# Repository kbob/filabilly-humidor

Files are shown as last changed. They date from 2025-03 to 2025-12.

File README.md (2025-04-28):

# FilaBilly Humidor

The FilaBilly Humidor (FBH) is a smart cabinet for 3D printer filament storage and humidity control.  It's based on an IKEA BILLY bookcase and contains an active dehumidifier.  It has lighting, environment sensors, and a display screen, and it is Internet enabled.

The FilaBilly Humidor is based on [ESPHome](https://esphome.io/).  It can be used as a standalone device or integrated into [Home Assistant](https://homeassistant.io/).

**Status:** Mostly vaporware.  Some materials have been acquired.

## FilaBilly Dehumidifier
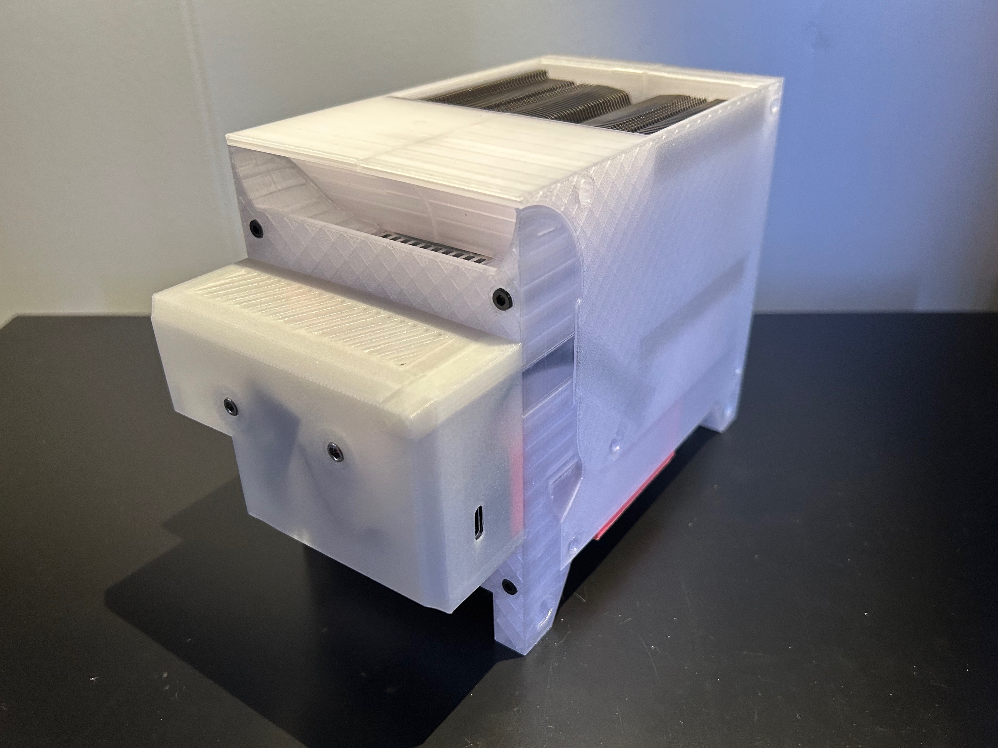
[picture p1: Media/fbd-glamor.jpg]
FilaBilly Dehumidifier


The FilaBilly Dehumidifier (FBD) is the dehumidifier component.  It is a compact active dehumidifier that is also Internet enabled.  The FBD can also be used without the FBH, either standalone or directly integrated into Home Assistant.  The FBD also uses ESPHome.

**Status:** Designed, printed, tested.

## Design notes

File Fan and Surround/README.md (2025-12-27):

# Fan and Surround

The Filabilly Humidor has a fan in the center shelf to move air from the lower to the upper chamber.  There is also a passive return for airflow in the opposite direction.  The `Fan Surround` directory has both.

The passive return surround holds a dummy fan that looks like another Noctua.  It's in the `Dummy Fan` directory.

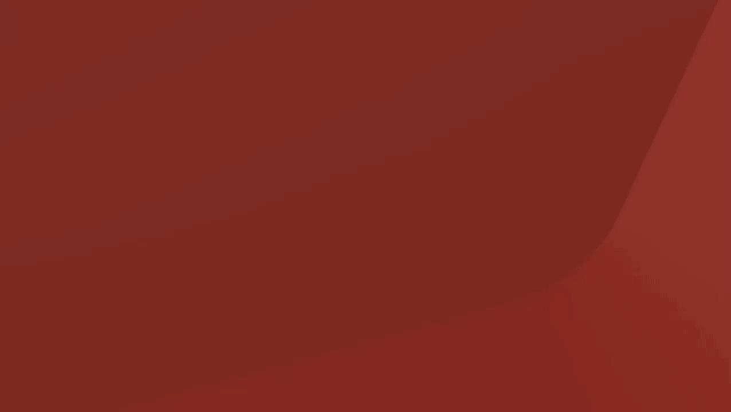
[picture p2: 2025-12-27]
Fan and Surround/Fan Surround/sequence.gif

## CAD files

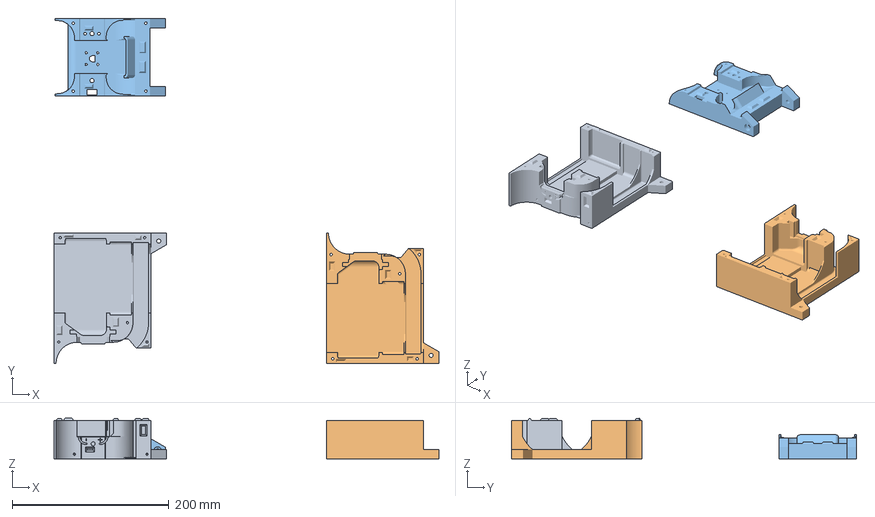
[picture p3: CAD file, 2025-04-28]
Dehumidifier/Printed Parts/3MF Files/PETG parts - 3 plates.3mf
491.8 x 440.7 x 52.2 mm
Housing Left Half.stl
Housing Right Half.stl
Housing Front.stl

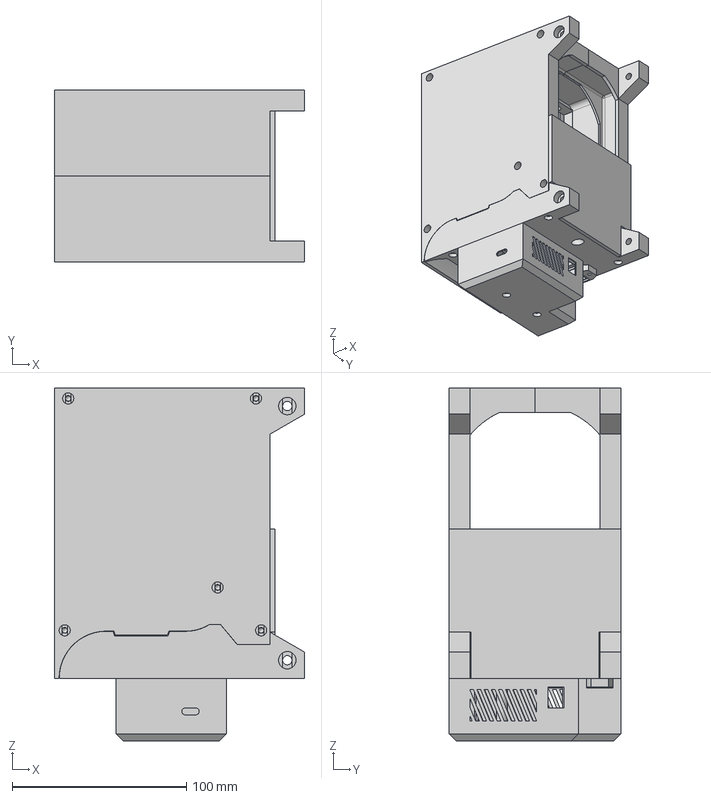
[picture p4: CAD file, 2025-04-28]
Dehumidifier/Printed Parts/CAD Files/Noctua Peltier Dehumidifier v37.step
143.8 x 98.7 x 202.7 mm
Seal Left
Seal Right
Electronics Cover
PCB Standoffs
Housing Right Half
Housing Left Half
Bottom Vent Slider

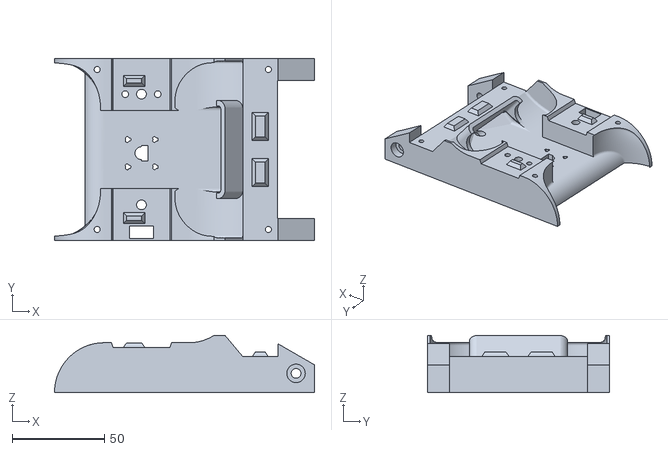
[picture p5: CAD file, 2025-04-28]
Dehumidifier/Printed Parts/STL Files/Housing Front.stl
141.0 x 98.7 x 30.9

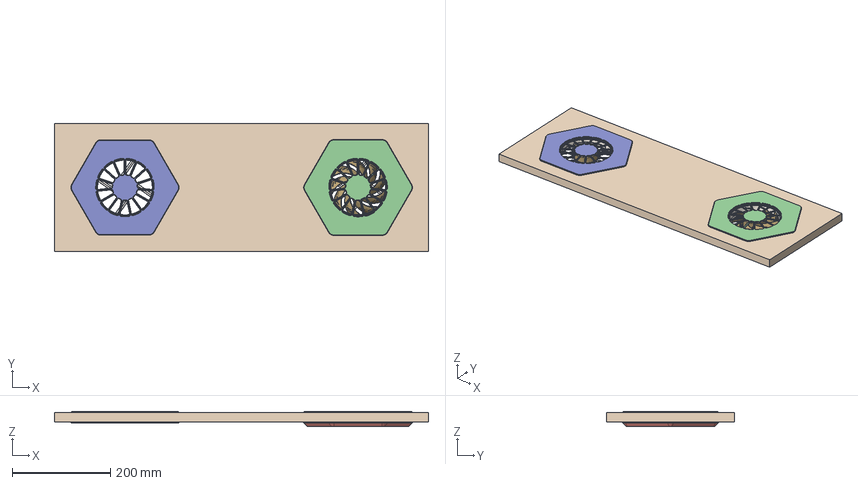
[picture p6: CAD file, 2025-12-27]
Fan and Surround/Dummy Fan/Shelf Fan Housing v15.step
760.0 x 260.0 x 29.5 mm
NOCTUA_NF-A12_FRAME
ANTI_VIBRATION_PAD x 8
NOCTUA_NF-A12_BLADES
FAN_HUB
Shelf
NOCTUA_NF-A12_FRAME_1
NOCTUA_NF-A12_BLADES_1
Dummy Surround

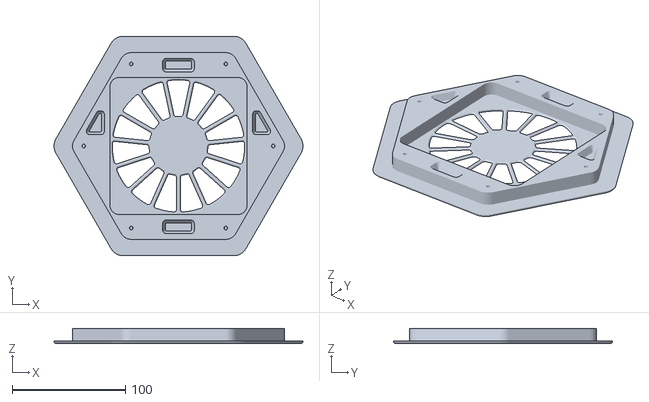
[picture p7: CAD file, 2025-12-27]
Fan and Surround/Fan Surround/Dummy Top.stl
220.0 x 193.9 x 13.0

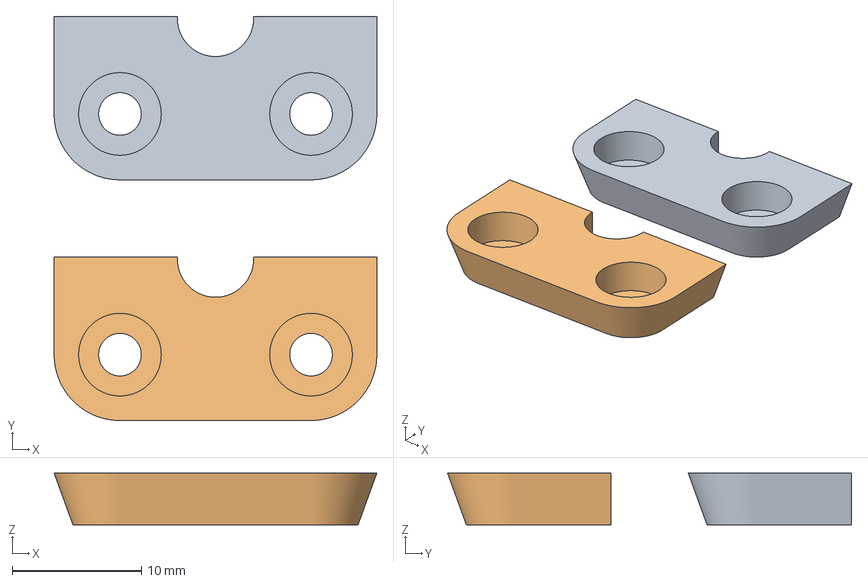
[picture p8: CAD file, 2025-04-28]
Dehumidifier/Printed Parts/3MF Files/TPU Parts - 1 plate.3mf
25.0 x 31.3 x 4.00 mm

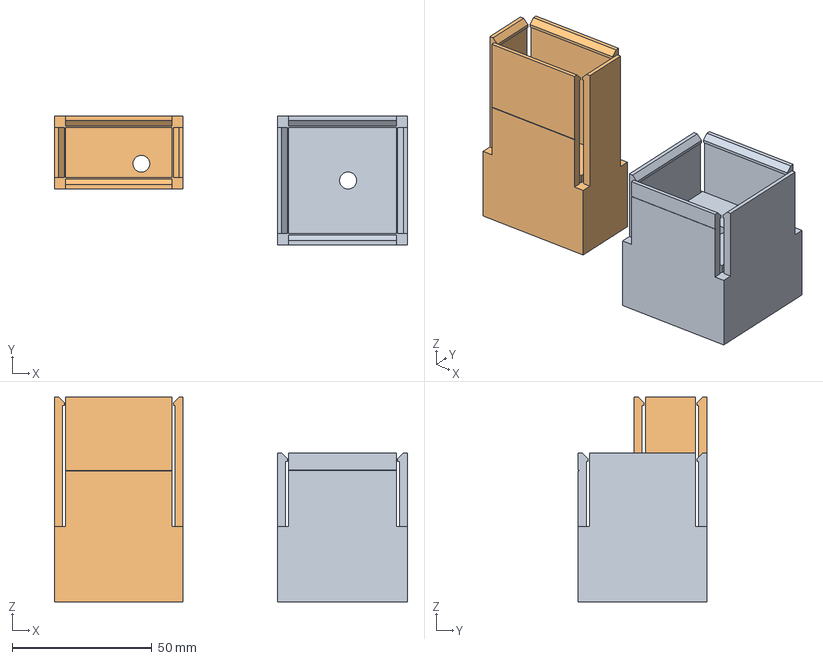
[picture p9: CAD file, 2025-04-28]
Dehumidifier/Printed Parts/CAD Files/Heatsink Drill Guide v4.step
126.2 x 46.0 x 73.2 mm

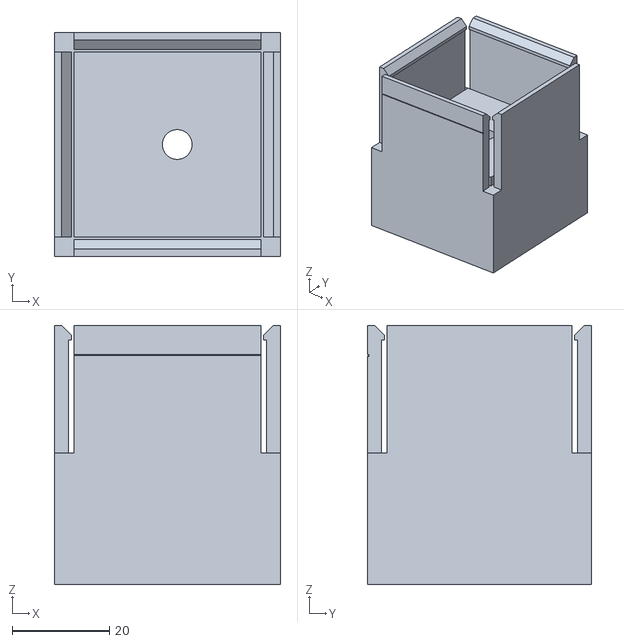
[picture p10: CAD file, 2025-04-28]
Dehumidifier/Printed Parts/STL Files/Heatsink Drill Guide.stl
46.5 x 46.0 x 53.2

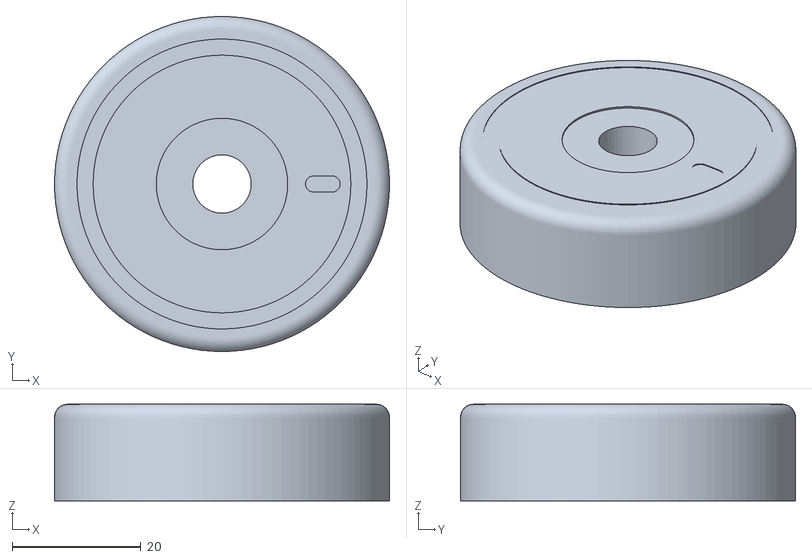
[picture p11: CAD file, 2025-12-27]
Fan and Surround/Dummy Fan/Dummy Fan Hub.stl
52.0 x 52.0 x 15.0

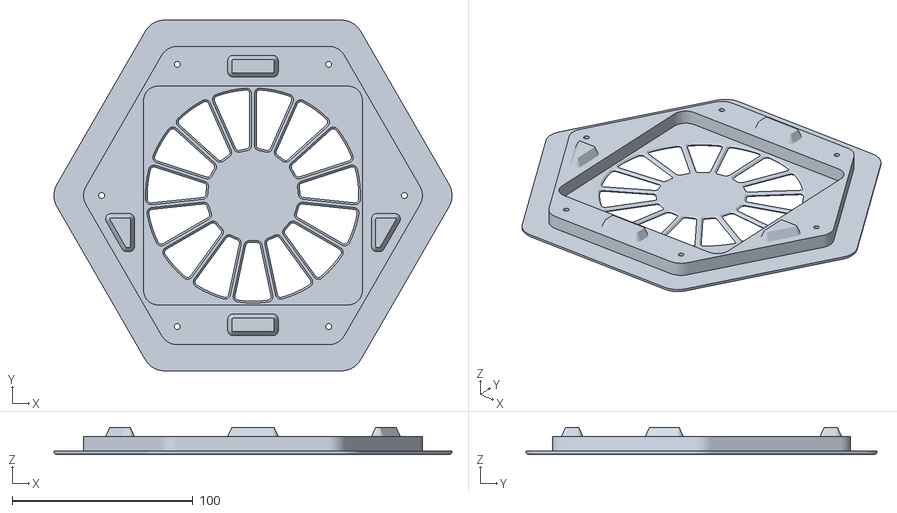
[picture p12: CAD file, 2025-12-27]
Fan and Surround/Fan Surround/Dummy Bottom.stl
220.0 x 193.9 x 15.0

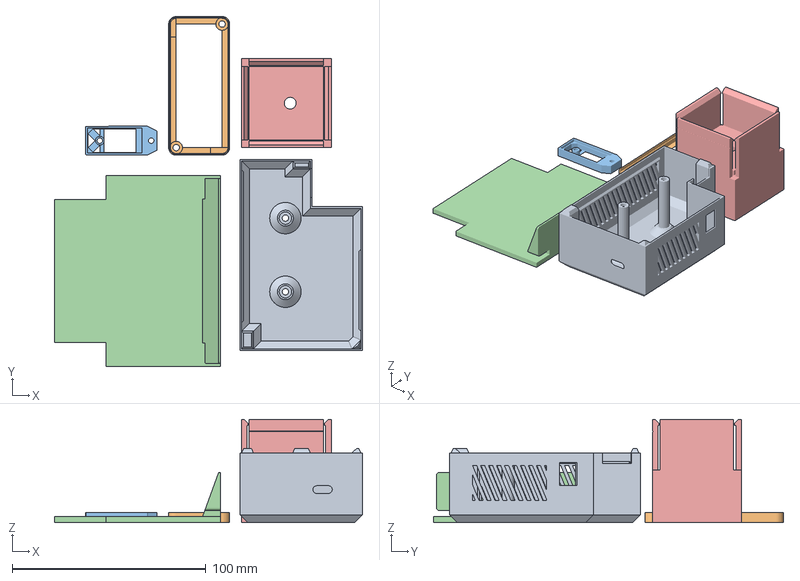
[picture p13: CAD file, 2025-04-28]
Dehumidifier/Printed Parts/3MF Files/PLA parts - 1 plate.3mf
159.0 x 180.7 x 53.2 mm
Electronics Cover.stl
PCB Standoff.stl
DHT22 Standoff.stl
Bottom Vent Slider.stl
Heatsink Drill Guide.stl

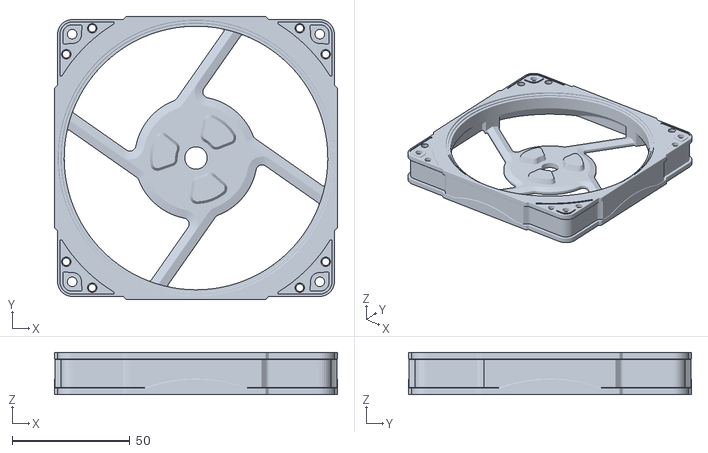
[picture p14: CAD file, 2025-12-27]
Fan and Surround/Dummy Fan/Dummy Fan Surround.stl
120.0 x 120.0 x 18.0

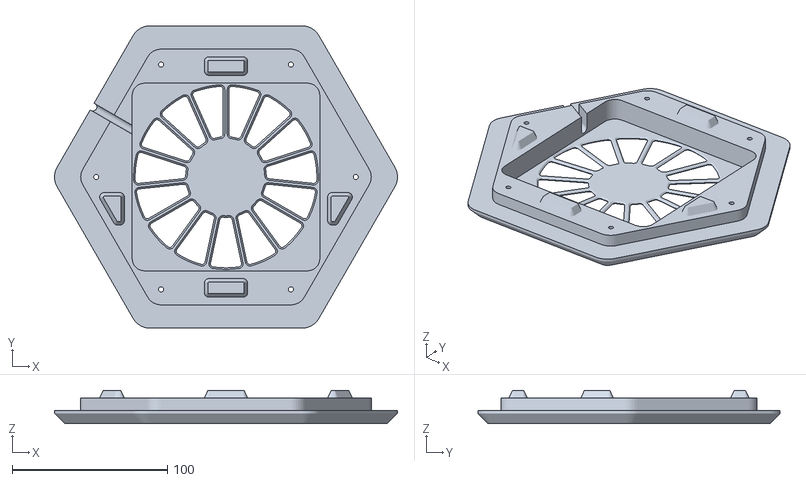
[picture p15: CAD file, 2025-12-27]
Fan and Surround/Fan Surround/Fan Housing Bottom.stl
221.1 x 194.9 x 21.5

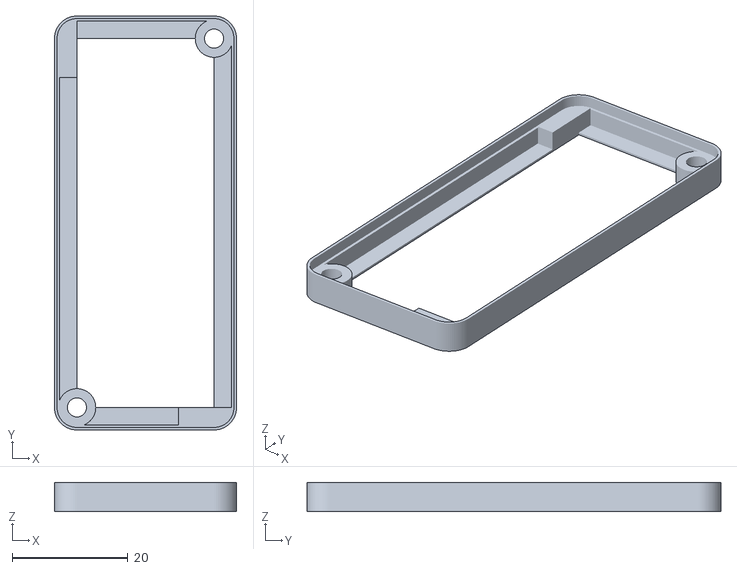
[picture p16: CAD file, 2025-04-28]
Dehumidifier/Printed Parts/STL Files/PCB Standoff.stl
31.5 x 71.6 x 5.10

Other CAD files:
Dehumidifier/Printed Parts/STL Files/2X Half Seal.stl
Fan and Surround/Fan Surround/Fan Housing Top.stl
Dehumidifier/Printed Parts/STL Files/Housing Left Half.stl
Fan and Surround/Fan Surround/Cutting Guide.stl
Dehumidifier/Printed Parts/CAD Files/Heatsink Drill Guide v4.f3d
Dehumidifier/Printed Parts/STL Files/Bottom Vent Slider.stl
Dehumidifier/Printed Parts/STL Files/DHT22 Standoff.stl
Dehumidifier/Printed Parts/STL Files/Electronics Cover.stl
Dehumidifier/Printed Parts/STL Files/Housing Right Half.stl

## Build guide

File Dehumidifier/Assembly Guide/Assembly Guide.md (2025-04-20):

# FilaBilly Dehumidifier Assembly Guide

## Overview

Welcome to the **FilaBilly Dehumidifier (FBD)**.  This is a compact smart device that extracts water from the air.  It is meant to be used in an airtight cabinet to create a low humidity environment to store 3D printer filament.

This is part of a larger project in progress, the **FilaBilly Humidor (FBH)**.  The FBH is based on the [FilaBilly](https://www.printables.com/model/660713-filabilly-filament-rack).  The FilaBilly turns an IKEA BILLY bookcase into a filament storage cabinet.  The FBH expands on the FilaBilly by sealing the cabinet and adding lighting, environment monitoring and control, and smart home integration.

The FilaBilly Dehumidifier is an ESPHome smart device based on an ESP32 micro controller.  It connects to your network using Wi-Fi.  You can control it directly with a web browser or integrate it into Home Assistant.  In the future, I intend to also be able to monitor and control it from the FilaBilly Humidor's micro controller.

The FilaBilly Dehumidifier includes a printed circuit board for the electronics.  All of the parts use through-holes[^1] for easy assembly, and all of the parts should be easy to source.

[^1]: With one exception. The optional QWIIC connector is surface mount.

The FilaBilly Dehumidifier is closely based on [Ben Krejci's filament dehumidifier](https://www.benkrejci.com/post/dehumidifier).  Ben gets credit for the overall design, the air and water routing through the box, and most of the ESPhome firmware.  I would have just used Ben's design except that he started with a CPU cooler that is no longer made.  So the FilaBilly Dehumidifier is designed to fit the Noctua NH-U9S cooler.

The FilaBilly Dehumidifier is a work in progress.  The mechanical assembly feels finished.  The ESPHome firmware is functional but missing some features.  I intend to design some brackets to clip it onto FilaBilly rails.  And the larger FilaBilly Humidor project is still mostly theoretical at this point.  Still, I'm publishing it in unfinished state because it's good enough to use.

## Bill of Materials

You will need these parts to build the FBD.  The Buy links are representative.  You may have parts on hand; you can certainly find the parts cheaper elsewhere.

### Printed Parts

| Quantity | Name | Material | Supports? |
|---:|:---|:---|:---:|
| 1 | Housing Left Half | PETG | Yes |
| 1 | Housing Right Half  | PETG | Yes |
| 1 | HeatsinkDrill Guide | any | - |
| 1 | Bottom Vent Slider  | any | Yes |
| 1 | Electronics Cover | any | - |
| 1 | PCB Standoff | any | - |
| 1 | DHT22 Standoff | any | - |
| 2 | Half Seal | TPU[^2]  | - |

[^2]: The seal halves will work best in TPU, but PETG may work.  They are designed to be deformed a little during assembly.  If you use PETG, you may have to file or trim them to fit.

### PCB Assembly Parts

The FBD includes a custom **printed circuit board (PCB)** to connect the ESP32 micro controller to the rest of the electronics.  This guide assumes you're familiar with the process of ordering PCBs and assembling electronics.  If not, the Internet is full of resources to get you started.

The PCB has space for a QWIIC connector, but it is not used.  If you want to add I²C peripherals such as an alternative humidity sensor, you can populate it.  You're on your own for mechanical packaging and ESPHome configuration if you do, though.

| Quantity | Description | Buy |
|---:|:---|:----|
| 1 | Printed Circuit Board | [OSH Park](https://oshpark.com/shared_projects/0QmItzAm) |
| 1 | MP1584 Regulator Module | [Amazon](https://www.amazon.com/dp/B08DHS5XVK) |
| 1 | IRLB8721 Power MOSFET | [Digikey](https://www.digikey.com/en/products/detail/infineon-technologies/irlb8721pbf/2127670) |
| 1 | PJ-102AH Barrel Jack | [Digikey](https://www.digikey.com/en/products/detail/same-sky-formerly-cui-devices/PJ-102AH/408448) |
| 1 | 2 pos 3.5mm terminal block | [Digikey](https://www.digikey.com/en/products/detail/w%C3%BCrth-elektronik/691214110002/2508516) |
| 2 | 7 pos female header 2.54mm | [Digikey](https://www.digikey.com/en/products/detail/sullins-connector-solutions/PPTC071LFBN-RC/810146) |
| 1 | 4 pos male header 2.54mm | [Digikey](https://www.digikey.com/en/products/detail/sullins-connector-solutions/PREC040SAAN-RC/2774814)<br>(40 pins, cut it to length) |
| 2 | 3 pos male header 2.54mm | (see above) |
| 4 | 2 pos male heder 2.54mm | (see above) |
| 1 | 10K 1/4w through hole resistor  | [Digikey](https://www.digikey.com/en/products/detail/stackpole-electronics-inc/CF14JT10K0/1741265) |
| 1 | 4.7K 1/4w through hole resistor | [Digikey](https://www.digikey.com/en/products/detail/stackpole-electronics-inc/CF14JT4K70/1741428) |

#### Optional

If you add the QWIIC connector, you will need these additional parts.

| Quantity | Description | Buy |
|---:|:---|:----|
| 2 | additional 4.7K resistors | (see above) |
| 1 | JST BM04B-SRSS-TB | [Digikey](https://www.digikey.com/en/products/detail/jst-sales-america-inc/BM04B-SRSS-TB/926696) |

### Other Parts

| Quantity | Description | Buy |
|---:|:---|:----|
| 1 | Noctua NH-U9S CPU Cooler | [Amazon](https://www.amazon.com/dp/B00TBHYYFK) |
| 1 | TEC-12705 Peltier Cooler | [Amazon](https://www.amazon.com/dp/B09GXDFW39) |
| 1 | aluminum heatsink, 40x40x20mm | [Amazon](https://www.amazon.com/dp/B07FXP35FW) |
| 1 | thermal paste | [Amazon](https://www.amazon.com/dp/B07L9BDY3T/) |
| 1 | Seeed XAIO ESP32C3 | [Seeed Studio](https://www.seeedstudio.com/Seeed-XIAO-ESP32C3-p-5431.html) |
| 1 | DHT22 temperature/humidity module | [Amazon](https://www.amazon.com/dp/B09TKTWXH1) |
| 1 | DS18B20 temperature probe | [Amazon](https://www.amazon.com/dp/B00M1PM55K) |
| 1 | 12V 5A power supply | [Amazon](https://www.amazon.com/dp/B0CW2PJQLJ/) |
| 1 | silicone tubing | [Amazon](https://www.amazon.com/dp/B0957KZVGG/) |
| 1 | 3 conductor female-female cable | [Amazon](https://www.amazon.com/dp/B07GD312VG)<br>(tear off three strands) |
| 2 | ferrules, 22awg | [Amazon](https://www.amazon.com/dp/B0BJD5796C) |
| 2 | M5 nylon lock nuts | |
| 2 | M5x30 SHCS machine screws | |
| 2 | M3x40 SHCS machine screws | |
| 4 | M3x30 SHCS machine screws | |
| 5 | M3x16 SHCS machine screws | |
| 2 | M3x10 SHCS machine screws | |
| 4 | M3x8 SHCS machine screws | |
| 2 | M2.5x10 SHCS machine screws | |

## Parts Preparation

### Deburr the PCB

If the PCB has "mouse bite" burrs around its edges, file them smooth until the PCB fits into the PCB Standoff printed part.

### Remove supports and clean parts

Remove the supports from the printed parts that have them.  The easiest way to clear supports from the tube in the Housing Right Half is to push them out with a long thin screwdriver.

It will also help to run screws through all the screw holes to clean them up until the screws slide through easily.  Don't clean up the blind holes &mdash; the screws need to bite into the plastic there.

Don't forget to clean the M5 holes in the dehumidifier feet.

### Drill heatsink

Use the Heatsink Drill Guide to drill a hole in between the fins of the heatsink.  Drill all the way to the heatsink base, but not beyond.  There is an etched line on the drill guide showing how far to drill.  Test fit the DS18B20 temperature probe and ensure it goes all the way in and contacts the heatsink base.  I used a 15/64" (5.95mm) bit, and I had to wobble it to enlarge the hole.  A 6mm bit would probably be ideal.

### Separate fan from CPU cooler

Unclip the wire clips from the Noctua NH-U9S CPU cooler and remove the fan.  Discard the clips.

### Remove clamp from CPU cooler

Insert a long Phillips screwdriver into the hole in the CPU cooler fans and unscrew the clamp.  Remove the clamp and discard it.

### Identify hot and cold sides of TEC

Briefly connect the TEC Peltier unit to a power supply and find out which side gets cold.  Label it or remember.  Mine has text printed on the cold side.

### Install ESPHome configuration

Before installing the XIAO into the FBD, install the ESPHome configuration and attach it to your Wi-Fi.  This guide doesn't cover ESPHome installation; see [the ESPHome documentation](https://esphome.io/) for info.

Verify that you can access the ESP32's web server now.

## Building the PCB Assembly

### Solder Components

Solder the components onto the PCB in this order.

 1. Male Headers.  You can use a breadboard to align most of the male headers while you solder them.
 2. Resistors
 3. QWIIC connector (optional)
 4. Female headers
 5. 5V regulator (MP1584)
 6. Terminal block
 7. Barrel jack
 8. Power MOSFET

### Set Voltage

Before attaching the XIAO, attach the 12V power supply and adjust the MP1584 regulator to 5 volts.

### Install XIAO

Plug the XIAO board in to the female headers.  Note that you should not attach the USB while the XIAO is in place.  For configuration updates, either use Wi-Fi or remove the XIAO before attaching USB.

## Assembly

This section shows the steps to assemble the parts.

### Insert M5 nuts

Insert the M5 nylon lock nuts into the housing halves.  Put an M5 screw through the hole, screw the nut onto it, and pull it back out until the nut is seated flush.

Note: the nuts are held in by friction.  Be careful not to dislodge them from here on.

### Insert NH-U9S into Housing Left Half

It will fit.  It has to be aligned just so, then it drops in.

### Insert fan into Housing Left Half

Orient the fan so the it blows air into the fins, and the cable is at the position shown.

### Affix TEC

Orient the TEC Peltier unit so that its hot side is against the CPU block and its wires fit into the slots in the Housing Left Half.  Apply enough thermal paste to make a thin layer over the whole mating surface and press it into place.
 
### Push Housing Right Half On

Feed the fan wire through the tunnel in the Housing Right Half.  Be careful not to pinch the wire, and lower the right half onto the assemblied parts.  It will fit.  When it does, it will drop on.  It may be slightly open at the back (1mm or less), that's okay.

### Screw the housing halves together

Use five M3x16 screws.  You should be able to pull the housing halves together to close any gap between them.  If not, something is probably pinched inside.  Open it up and correct the problem.

### Attach the Bottom Vent Slider

Put the Bottom Vent Slider in diagonally, then rotate it into position.

The vent slider is adjustable.  Start with it covering about half of the fan.

### Affix the heatsink and temperature probe

Push the temperature probe all the way into the heatsink so that it is contacting the heatsink base.  Orient the heatsink so that the fins are horizontal and the probe is slightly above center.  Apply thermal paste and stick it on.

### Attach the Housing Front

Feed the four wires through the holes in the Housing Front.  Push the Housing Front against the rest of the assembly.  Verify that the temperature probe lines up with its hole.

**Carefully** insert the M3x30 screws into the big holes and engage the nuts.  Do not push the nuts out of place.  Screw the screws down but not tight yet.

Insert four M3x30 screws into the four small holes and tighten them.  Then go back and tighten the M5 screws until the gap between the Housing Front and the Housing Left/Right Half is closed.

The M5 screws press the heatsink, TEC, and CPU cooler together to ensure a good thermal bond.

### Seal the temperature probe hole

Put the two Half Seals in and screw them down with four M3x8 screws.

Note.  The probe should stick out about as far as shown.  If it's more, then the probe may not be against the heatsink base.

### Install PCB, DHT22, and standoffs

Fit the PCB and the DHT22 into their standoffs.  Note the orientation of the PCB on its standoff.  Attach the PCB with two M3x10 screws, and attach the DHT22 with two M2.5x10 screws.

### Connect TEC wires

Cut the wires to length.  Install a ferrule on each wire.  Screw the ferrules into the terminal block on the PCB, and mind the polarity.

Note that the holes in the Housing Front are big enough to pass the ferrules through if you need to disassemble the dehumidifier.

### Connect temperature probe wires

Cut the wires on the DS18B20 temperature probe to length.  Crimp on 3 female Dupont pins and a connector.  Note the pinout as shown in the schematic or back side of the PCB.  Plug it into the PCB.

### Connect fan wires

The fan already has a compatible connector.  Note that Pin 1 on the connector is Pin 4 on the PCB.  Check the pinout.

### Connect DHT22 wires

Use the female-to-female cable to attach the DHT22 to the PCB.  Note the pinout.

### Attach the Electronics Cover

No, really.  Leave the Electronics Cover off for now.  You'll need access.  Just verify that it fits.  You'll have to mash things together; don't pinch the antenna or any wires.  Secure the cover with two M3x40 screws.

### Attach the drain tube

Spread some silicone caulk around the tip of the drain tube, then insert it into the drain hole.  Let it set according to the caulk instructions.

### Test

Dunno.  Mine worked on the first try, because I'd tested everything on a breadboard.  Attach power, look for smoke, listen for the fan, put your finger on the heatsink and see whether it's getting cold.  Connect to the ESP32's web server and see whether the sensor values look sane.  Try turning it off and on from the web interface.  Debug as needed.

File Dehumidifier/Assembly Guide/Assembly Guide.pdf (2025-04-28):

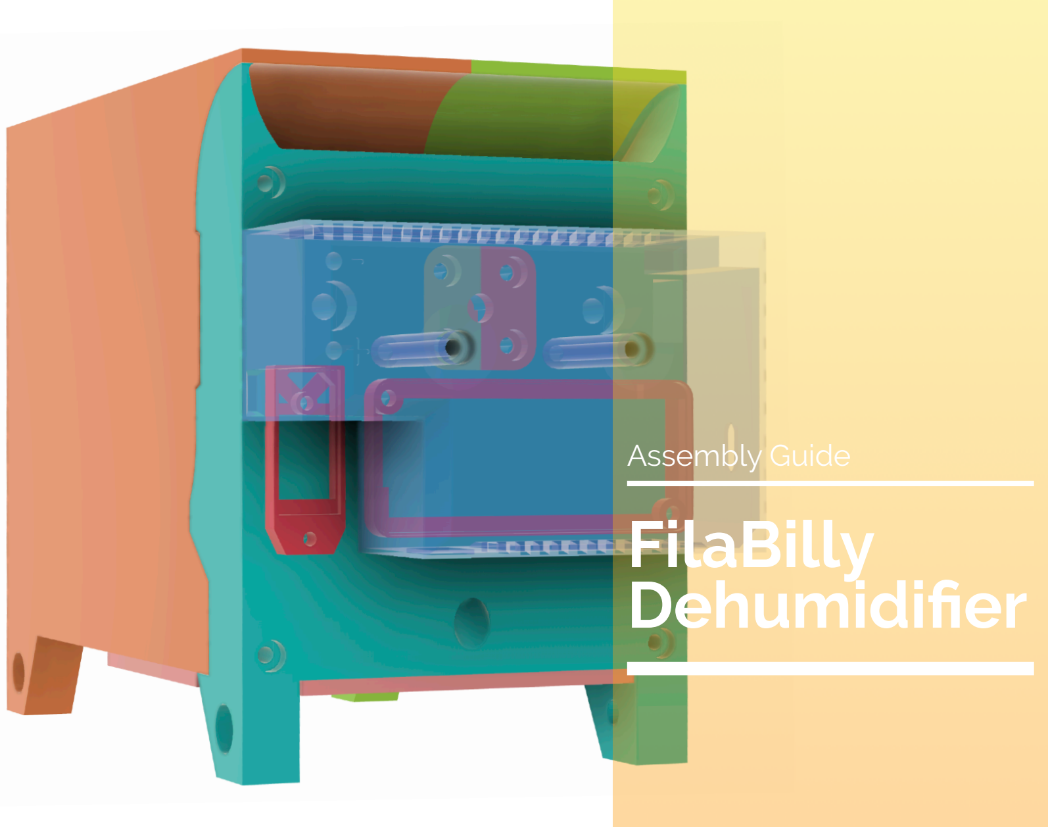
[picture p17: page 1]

# FilaBilly Dehumidifier

## Assembly Guide

## Overview

Welcome to the FilaBilly Dehumidifier (FBD). This is a compact smart device that extracts water from the air. It is meant to be used in an airtight cabinet to create a low humidity environment to store 3D printer filament.

This is part of a larger project in progress, the FilaBilly Humidor (FBH). The FBH is based on the FilaBilly. (https://www.printables.com/model/660713-filabilly-filament-rack) The FilaBilly turns an IKEA BILLY bookcase into a filament storage cabinet. The FBH expands on the FilaBilly by sealing the cabinet and adding lighting, environment monitoring and control, and smart home integration.

The FilaBilly Dehumidifier is an ESPHome smart device based on an ESP32 micro controller. It connects to your network using Wi-Fi. You can control it directly with a web browser or integrate it into Home Assistant. In the future, I intend to also be able to monitor and control it from the FilaBilly Humidor's micro controller.

The FilaBilly Dehumidifier includes a printed circuit board for the electronics. All of the parts use through-holes¹ for easy assembly , and all of the ¹ parts should be easy to source.

The FilaBilly Dehumidifier is closely based on Ben Krejci's filament dehumidifier. (https://www.benkrejci.com/post/dehumidifier) Ben gets credit for the overall design, the air and water routing through the box, and most of the ESPhome firmware. I would have just used Ben's design except that he started with a CPU cooler that is no longer made. So the FilaBilly Dehumidifier is designed to fit the Noctua NH-U9S cooler.

The FilaBilly Dehumidifier is a work in progress. The mechanical assembly feels finished. The ESPHome firmware is functional but missing some features. I intend to design some brackets to clip it onto FilaBilly rails. And the larger FilaBilly Humidor project is still mostly theoretical at this point. Still, I'm publishing it in unfinished state because it's good enough to use.

With one exception. The optional QWIIC connector is surface mount. ¹ Page 2 of 35

## Bill of Materials

You will need these parts to build the FBD. The Buy links are representative. You may have parts on hand; you can certainly find the parts cheaper elsewhere.

### Printed Parts

The seal halves will work best in TPU, but PETG may work. They are designed to be deformed a little during assembly. If you use PETG, you may have to file or trim them to fit.

Page 3 of 35

Quantity | Name | Material | Supports?
1 | Housing Left Half | PETG | Yes
1 | Housing Right Half | PETG | Yes
1 | Housing Front | PETG | Yes
1 | Electronics Cover | any | -
1 | PCB Standoff | any | -
1 | DHT22 Standoff | any | -
1 | Bottom Vent Slider | any | Yes
1 | Heatsink Drill Guide | any | -
2 | Half Seal | TPU | -

### PCB Assembly Parts

The FBD includes a custom printed circuit board (PCB) to connect the ESP32 micro controller to the rest of the electronics. This guide assumes you're familiar with the process of ordering PCBs and assembling electronics. If not, the Internet is full of resources to get you started.
Quantity | Description | Buy
1 | Printed Circuit Board | OSH Park (https://oshpark.com/shared_projects/0QmItzAm)
1 | MP1584 Regulator Module | Amazon (https://www.amazon.com/dp/B08DHS5XVK)
1 | IRLB8721 Power MOSFET | Digikey (https://www.digikey.com/en/products/detail/infineon-technologies/irlb8721pbf/2127670)
1 | PJ-102AH Barrel Jack | Digikey (https://www.digikey.com/en/products/detail/same-sky-formerly-cui-devices/PJ-102AH/408448)
1 | 2 pos 3.5mm terminal block | Digikey (https://www.digikey.com/en/products/detail/w%C3%BCrth-elektronik/691214110002/2508516)
2 | 7 pos female header 2.54mm | Digikey (https://www.digikey.com/en/products/detail/sullins-connector-solutions/PPTC071LFBN-RC/810146)
1 | 4 pos male header 2.54mm | Digikey (https://www.digikey.com/en/products/detail/sullins-connector-solutions/PREC040SAAN-RC/2774814) (40 pins, cut it to length)
2 | 3 pos male header 2.54mm | (see above)
4 | 2 pos male heder 2.54mm | (see above)
1 | 10K 1/4w through hole resistor | Digikey (https://www.digikey.com/en/products/detail/stackpole-electronics-inc/CF14JT10K0/1741265)
1 | 4.7K 1/4w through hole resistor | Digikey (https://www.digikey.com/en/products/detail/stackpole-electronics-inc/CF14JT4K70/1741428) Page 4 of 35

### Optional PCB Parts

The PCB has space for a QWIIC connector, but it is not used. If you want to add I²C peripherals such as an alternative humidity sensor, you can populate it.

You're on your own for mechanical packaging and ESPHome configuration if you do, though. If you add the QWIIC connector, you will need these additional parts.

Page 5 of 35

Quantity | Description | Buy
2 | additional 4.7K resistors | (see above)
1 | JST BM04B-SRSS-TB | Digikey (https://www.digikey.com/en/products/detail/jst-sales-america-inc/BM04B-SRSS-TB/926696)

### Other Parts

Page 6 of 35

Quantity | Description | Buy
1 | Noctua NH-U9S CPU Cooler | Amazon (https://www.amazon.com/dp/B00TBHYYFK)
1 | TEC-12705 Peltier Cooler | Amazon (https://www.amazon.com/dp/B09GXDFW39)
1 | aluminum heatsink, 40x40x20mm | Amazon (https://www.amazon.com/dp/B07FXP35FW)
1 | thermal paste | Amazon (https://www.amazon.com/dp/B07L9BDY3T/)
1 | Seeed XAIO ESP32C3 | Seeed Studio (https://www.seeedstudio.com/Seeed-XIAO-ESP32C3-p-5431.html)
1 | DHT22 temperature/humidity module | Amazon (https://www.amazon.com/dp/B09TKTWXH1)
1 | DS18B20 temperature probe | Amazon (https://www.amazon.com/dp/B00M1PM55K)
1 | 12V 5A power supply | Amazon (https://www.amazon.com/dp/B0CW2PJQLJ/)
1 | silicone tubing | Amazon (https://www.amazon.com/dp/B0957KZVGG/)
1 | 3 conductor female-female cable | Amazon (https://www.amazon.com/dp/B07GD312VG) (tear off three strands)
2 | ferrules, 22awg | Amazon (https://www.amazon.com/dp/B0BJD5796C)

Continued on next page

Page 7 of 35

Other Parts, continued
Quantity | Description | Buy
2 | M5 nylon lock nuts
2 | M5×30 SHCS machine screws
2 | M3×40 SHCS machine screws
4 | M3×30 SHCS machine screws
5 | M3×16 SHCS machine screws
2 | M3×10 SHCS machine screws
4 | M3×8 SHCS machine screws
2 | M2.5x10 SHCS machine screws

## Parts Preparation

### Deburr the PCB

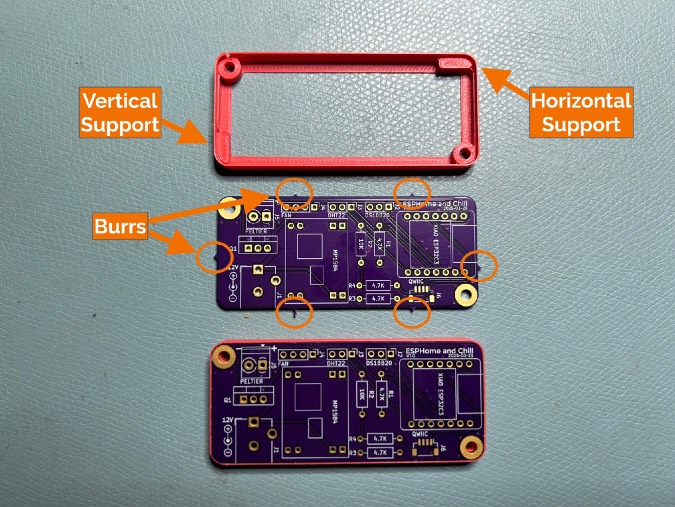
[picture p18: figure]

If the PCB has “mouse bite” burrs around its edges, trim and file them smooth until the PCB fits into the PCB Standoff printed part. Note the standoff orientation. The horizontal support goes under the "ESPHome and Chill" text, and the vertical support goes under the barrel jack polarity mark.

Page 8 of 35

### Remove supports and clean parts

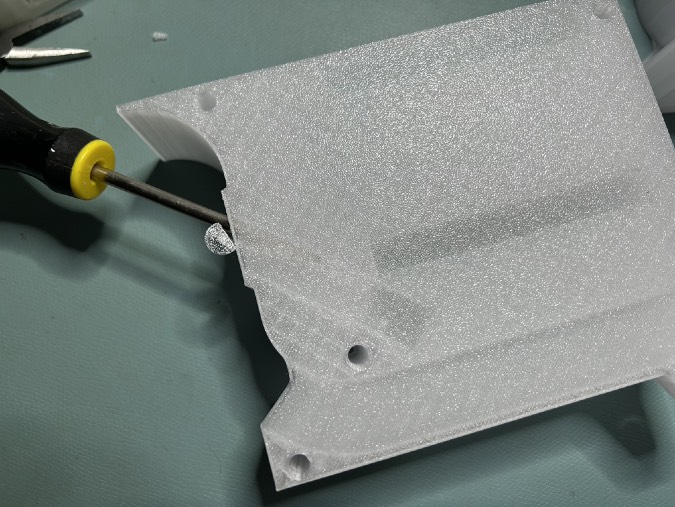
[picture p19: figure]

Remove the supports from the printed parts that have them. The easiest way to clear supports from the tube in the Housing Right Half is to push them out with a long thin screwdriver.

It will also help to run screws through all the screw holes to clean them up until the screws slide through easily. Don't clean up the blind holes — the screws need to bite into the plastic there.

Don't forget to clean the M5 holes in the dehumidifier feet.

Page 9 of 35

### Drill heatsink

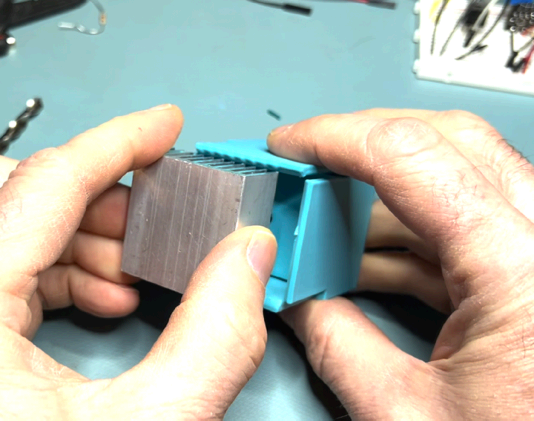
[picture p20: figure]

Use the Heatsink Drill Guide to drill a hole in between the fins of the heatsink. Put the heatsink into the drill guide fins down. Orient it so the drill hole does not hit the center fin. The heatsink will snap into place.

Drill through the hole, all the way to the heatsink base, but not beyond. There is an etched line on the drill guide showing how far to drill.

Test fit the DS18B20 temperature probe and ensure it goes all the way in and contacts the heatsink base. I used a 15/64" (5.95mm) drill bit, and I had to wobble it to enlarge the hole. A 6mm bit would probably be ideal.

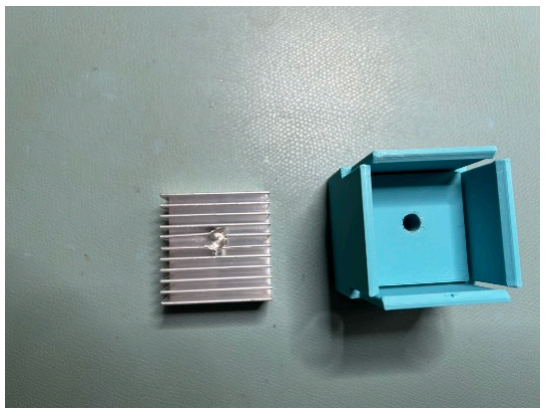
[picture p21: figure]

Page 10 of 35

### Separate fan from CPU cooler

Unclip the wire clips from the Noctua NH-U9S CPU cooler and remove the fan. Discard the clips.

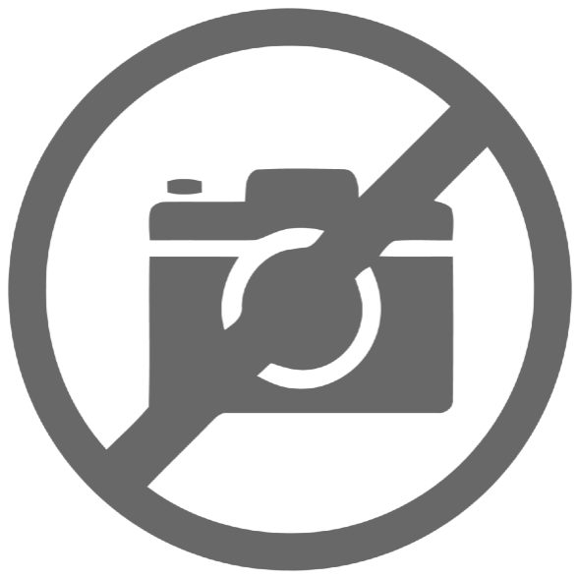
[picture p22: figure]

Page 11 of 35

No photo, sorry.

### Remove clamp from CPU cooler

Insert a long Phillips screwdriver into the hole in the CPU cooler fans and unscrew the clamp. Remove the clamp and discard it.

Page 12 of 35

No photo, sorry.

### Identify hot and cold sides of TEC

Briefly connect the TEC Peltier unit to a power supply and find out which side gets cold. Label it or remember. Mine has text printed on the cold side.

Page 13 of 35

No photo, sorry.

### Install ESPHome configuration

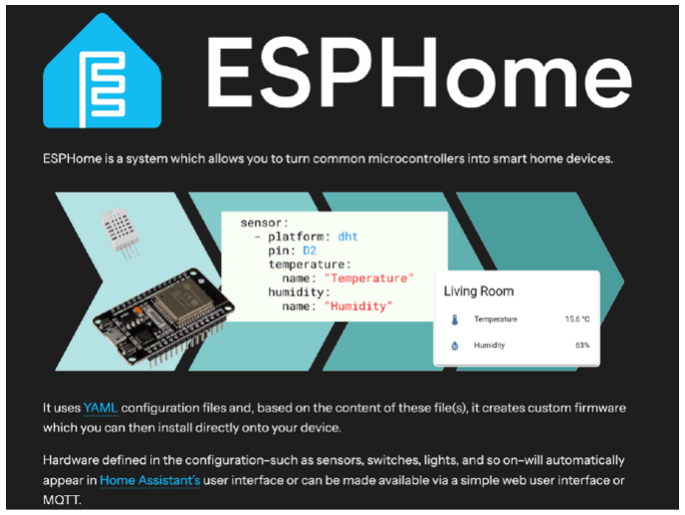
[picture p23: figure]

Before installing the XIAO into the FBD, install the ESPHome configuration and attach it to your Wi-Fi. This guide doesn't cover ESPHome installation; see the ESPHome documentation (https://esphome.io/) for info.

Verify that you can access the ESP32's web server.

Page 14 of 35

## Building the PCB Assembly

### Solder Components

Solder the components onto the PCB in this order.

1. Male Headers. You can use a breadboard to align most of the male headers while you solder them.
2. Resistors
3. QWIIC connector (optional)
4. Female headers
5. 5V regulator (MP1584)
6. Terminal block
7. Barrel jack
8. Power MOSFET

### Set Voltage

Before attaching the XIAO, attach the 12V power supply and adjust the MP1584 regulator to 5 volts.

### Install XIAO

Ensure the XIAO already has ESPHome configured. Plug the XIAO board in to the female headers.

Page 15 of 35

## Assembly

This section shows the steps to assemble the parts.

### Insert M5 nuts

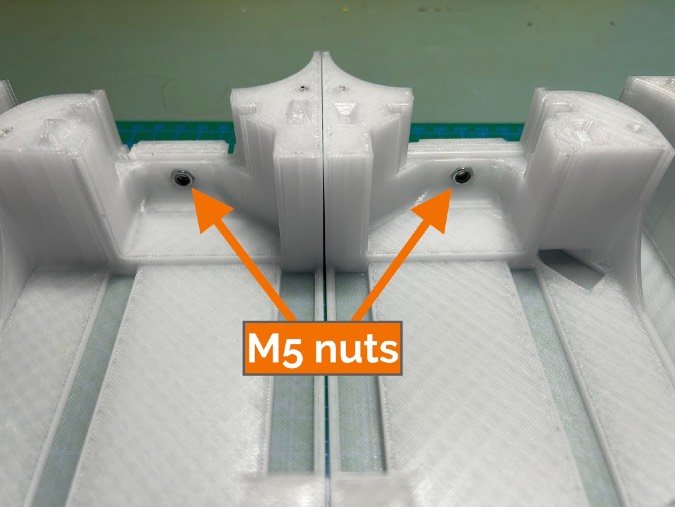
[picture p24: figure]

Insert the M5 nylon lock nuts into the housing halves. Put an M5 screw through the hole, screw the nut onto it, and pull it back out until the nut is seated flush.

The nuts are held in by friction. Be careful not to dislodge them from here on.

Page 16 of 35

### Insert NH-U9S into Housing Left Half

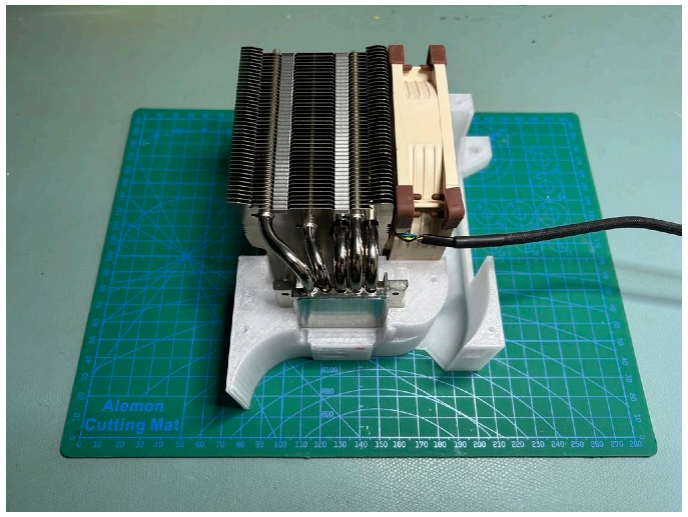
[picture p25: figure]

It will fit. It has to be aligned just so, then it drops in.

Page 17 of 35

### Insert fan into Housing Left Half

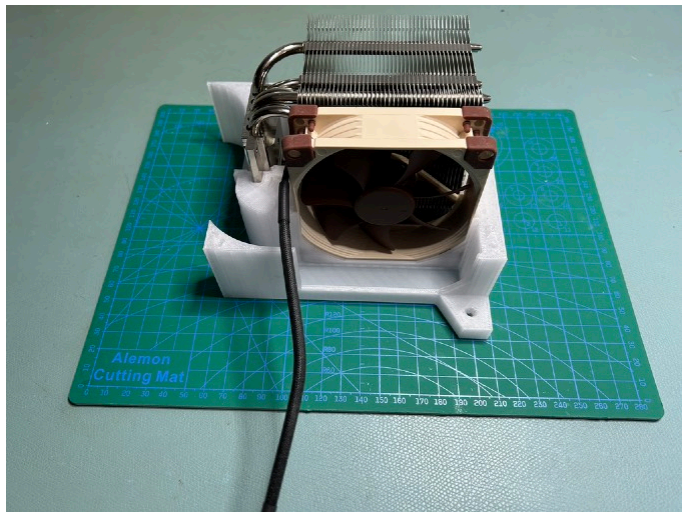
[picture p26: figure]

Orient the fan so the it blows air into the fins, and the cable is at the position shown.

Page 18 of 35

### Affix TEC

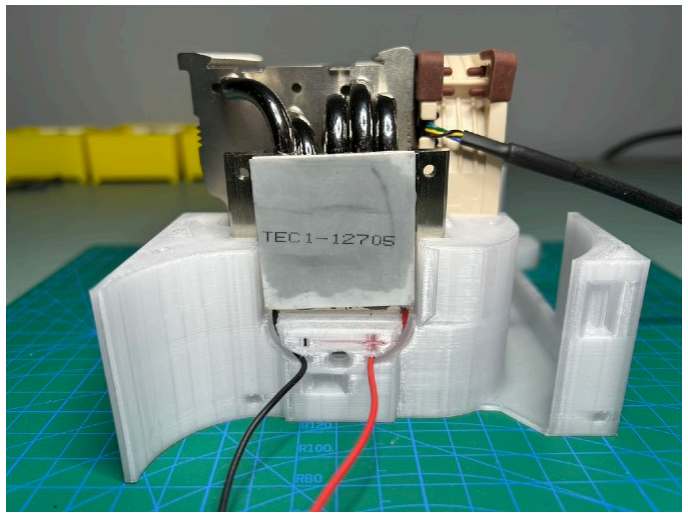
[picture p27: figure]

Orient the TEC Peltier unit so that its hot side is against the CPU block and its wires fit into the slots in the Housing Left Half. Apply enough thermal paste to make a thin layer over the whole mating surface and press it into place.

Page 19 of 35

### Push Housing Right Half On

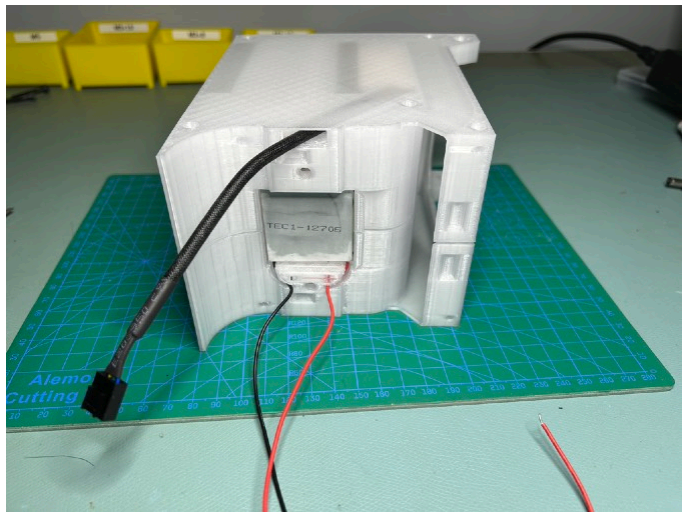
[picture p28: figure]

Feed the fan wire through the tunnel in the Housing Right Half. Lower the right half onto the assembly. It will fit. When it does, it will drop on. It may be slightly open at the back (1mm or less), that's okay.

Be careful not to pinch the fan wire.

Page 20 of 35

### Screw the housing halves together

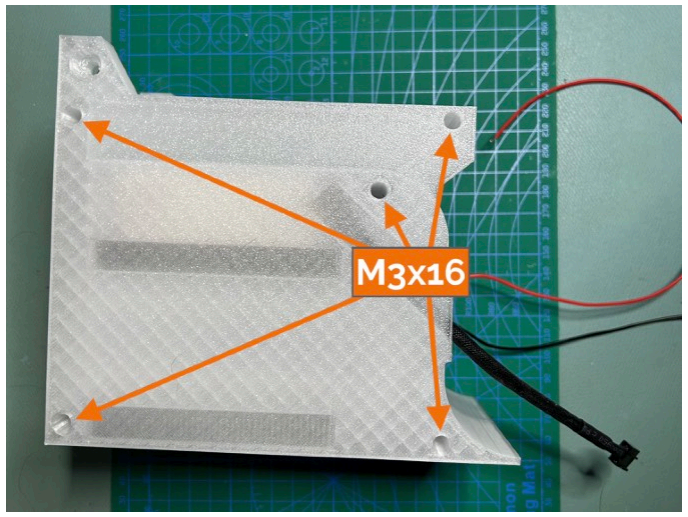
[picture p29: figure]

Use five M3×16 screws. You should be able to pull the housing halves together to close any gap between them. If not, something is probably pinched inside. Open it up and correct the problem.

Page 21 of 35

### Attach the Bottom Vent Slider

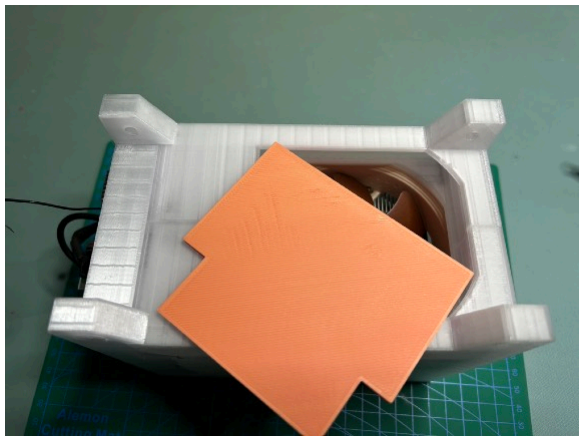
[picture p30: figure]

Put the Bottom Vent Slider in diagonally, then rotate it into position.

The vent slider is adjustable. Start with it covering about half of the fan.

Page 22 of 35

### Affix the heatsink and temperature probe

Push the temperature probe all the way into the heatsink so that it is contacting the heatsink base.
Orient the heatsink so that the fins are horizontal
and the probe is slightly above center. Apply thermal paste and stick it on.

Page 23 of 35

### Attach the Housing Front

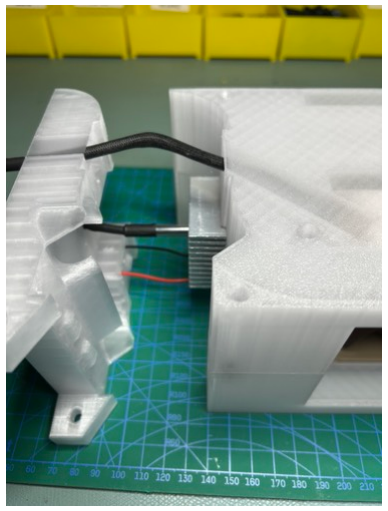
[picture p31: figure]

Feed the four wires through the holes in the Housing Front. Push the Housing Front against the rest of the assembly. Verify that the temperature probe lines up with its hole.
Carefully insert the M5×30 screws into the big holes and engage the nuts. Do not push the nuts out of place. Screw the screws down but not tight yet.

Insert four M3×30 screws into the four small holes and tighten them. Then go back and tighten the M5 screws until the gap between the Housing Front and the Housing Left/Right Half is closed.

The M5 screws press the heatsink, TEC, and CPU cooler together to ensure a good thermal bond.

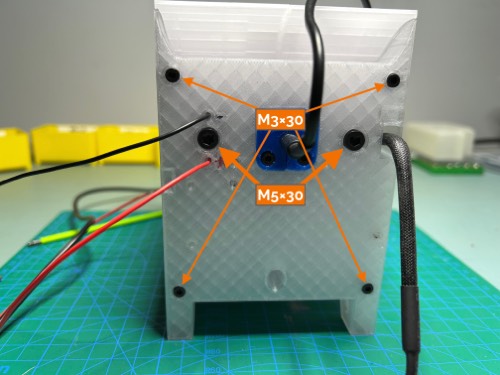
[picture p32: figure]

Page 24 of 35

### Seal the temperature probe hole

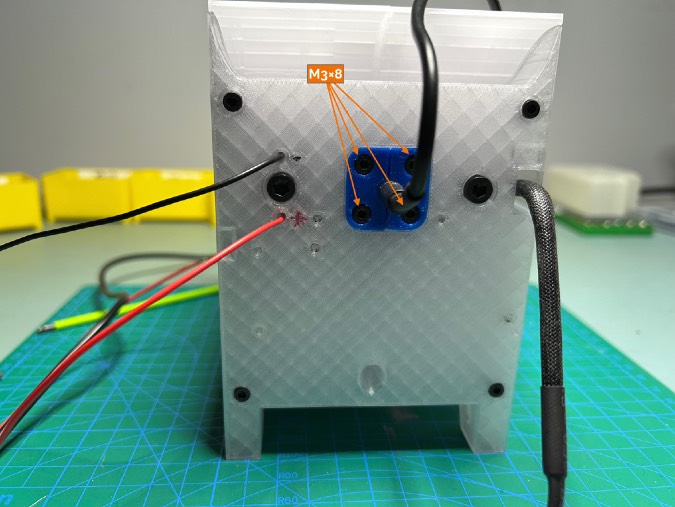
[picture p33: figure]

Put the two Half Seals in and screw them down with four M3×8 screws.

The probe should stick out about as far as shown on the next page. If it's more, then the probe may not be against the heatsink base.

Page 25 of 35

### Install PCB, DHT22, and standoffs

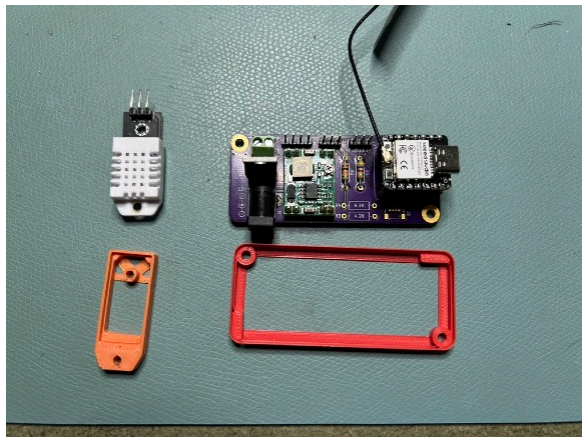
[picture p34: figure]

Fit the PCB and the DHT22 into their standoffs. Note the orientation of the PCB on its standoff: the horizontal support goes under the upper right corner. Attach the PCB with two M3×10 screws, and attach the DHT22 with two M2.5x10 screws.

Note the orientation of the PCB standoff.

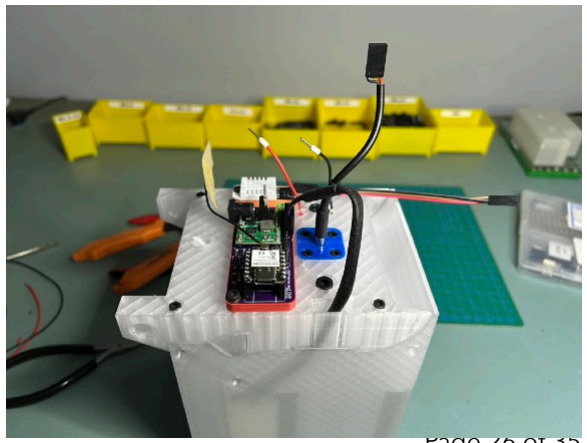
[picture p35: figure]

Page 26 of 35

### Connect TEC wires

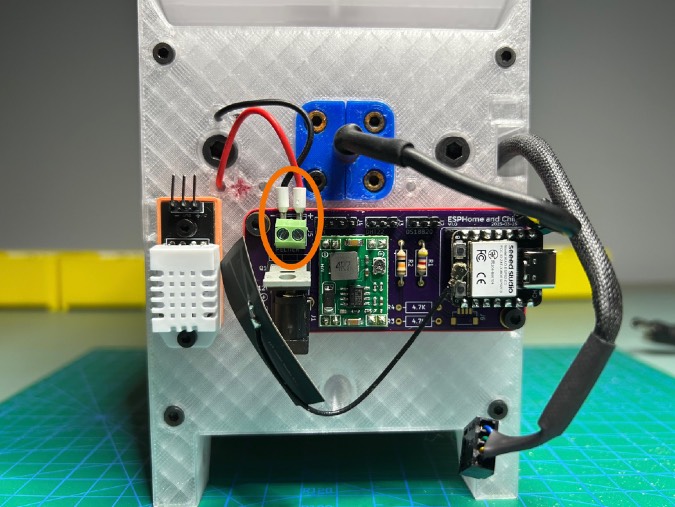
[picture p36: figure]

Cut the wires to length. Install a ferrule on each wire. Screw the ferrules into the terminal block on the PCB, and mind the polarity.

Note that the holes in the Housing Front are big enough to pass the ferrules through if you need to disassemble the dehumidifier.

Check the polarity. The positive (red) lead goes on the right.

Page 27 of 35

### Connect temperature probe wires

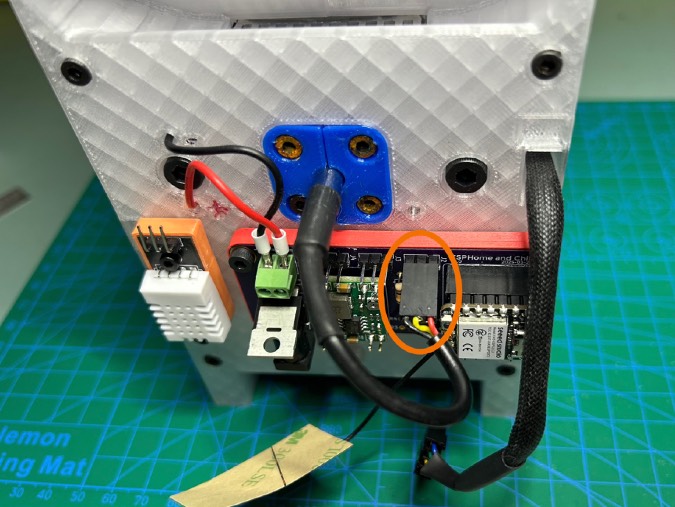
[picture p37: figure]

Cut the wires on the DS18B20 temperature probe to length. Crimp on 3 female Dupont pins and a connector. Note the pinout as shown in the schematic or back side of the PCB. Plug it into the PCB.

Page 28 of 35

### Connect fan wires

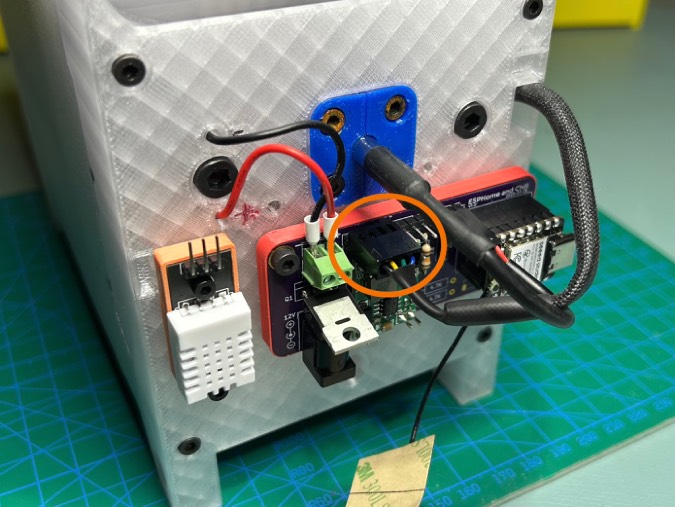
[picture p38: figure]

The fan already has a compatible connector. Plug it in.

Note that Pin 1 on the connector is Pin 4 on the PCB. Check the pinout.

Page 29 of 35

### Connect DHT22 wires

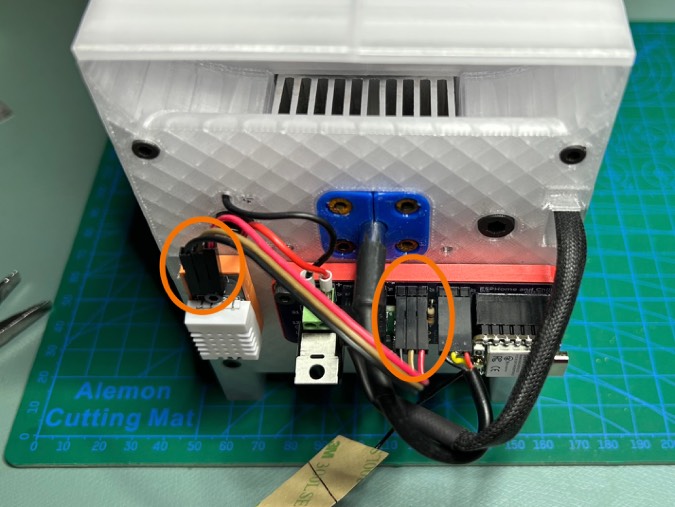
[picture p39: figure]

Use the female-to-female cable to attach the DHT22 to the PCB. Note the pinout.

Page 30 of 35

### Attach the Electronics Cover

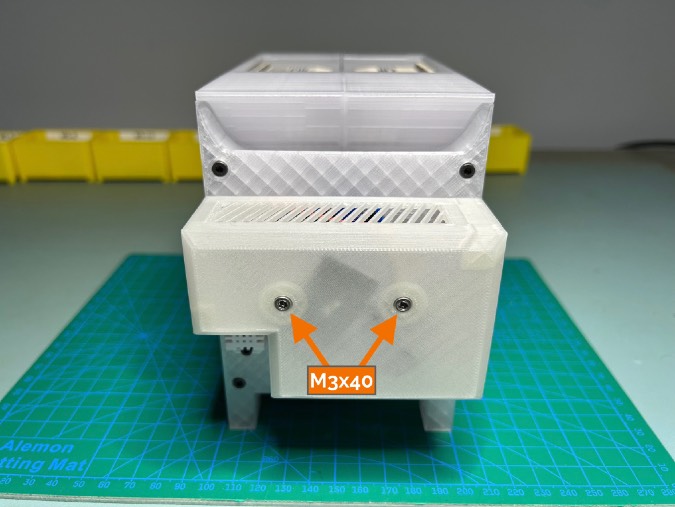
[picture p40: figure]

No, really. Leave the Electronics Cover off for now. You'll need access. Just verify that it fits. You'll have to mash things together; don't pinch the antenna or any wires. When you're ready, secure the cover with two M3×40 screws.

Page 31 of 35

### Attach the drain tube

Spread some silicone caulk around the tip of the drain tube, then insert it into the drain hole. Let it set according to the caulk instructions.

Page 32 of 35

No photo, sorry.

### Test

Dunno. Mine worked on the first try, because I'd tested everything on a breadboard. Attach power, look for smoke, listen for the fan, put your finger on the heatsink and see whether it's getting cold. Connect to the ESP32's web server and see whether the sensor values look sane. Try disabling it from the web interface. Debug as needed.

Let it run for a while. Within 15 minutes, you should see water in the drain tube.

Do not plug in the USB cable and 12 volt power supply at the time time. You risk back-powering your PC through the USB port.

Page 33 of 35

### Tune the System

There are several variables to adjust to optimize your dehumidifier's performance.

- fan speed
- bottom vent opening
- the ESPHome chiller's PID controller parameters

No two dehumidifiers will perform exactly the same. Variations in thermal paste application, compression screw tightness, vent opening size, and other things will affect it. So you should check how it's performing.

Open the web interface and click "show more".

Here are some guidelines.

- Keep the fan at 100% unless it's too loud for your space.
- Set the vent opening so the chiller power averages around 80-85%. Larger vent openings require less power.
- You can tune the PID controller using the web interface's auto-tune button. You can manually tune it by editing the config file.

Page 34 of 35

Page 35 of 35

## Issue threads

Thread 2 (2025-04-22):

Dehumidifier PCB should swap locations of J2 and J4.

kbob, 2025-04-22:
It would make the wiring less messy.

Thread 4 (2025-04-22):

Dehumidifier PCB should have a jumper to disconnect 5V power from ESP32.

kbob, 2025-04-22:
A power disconnect would make it possible to connect a USB cable without worrying about backpowering the PC on the other end.

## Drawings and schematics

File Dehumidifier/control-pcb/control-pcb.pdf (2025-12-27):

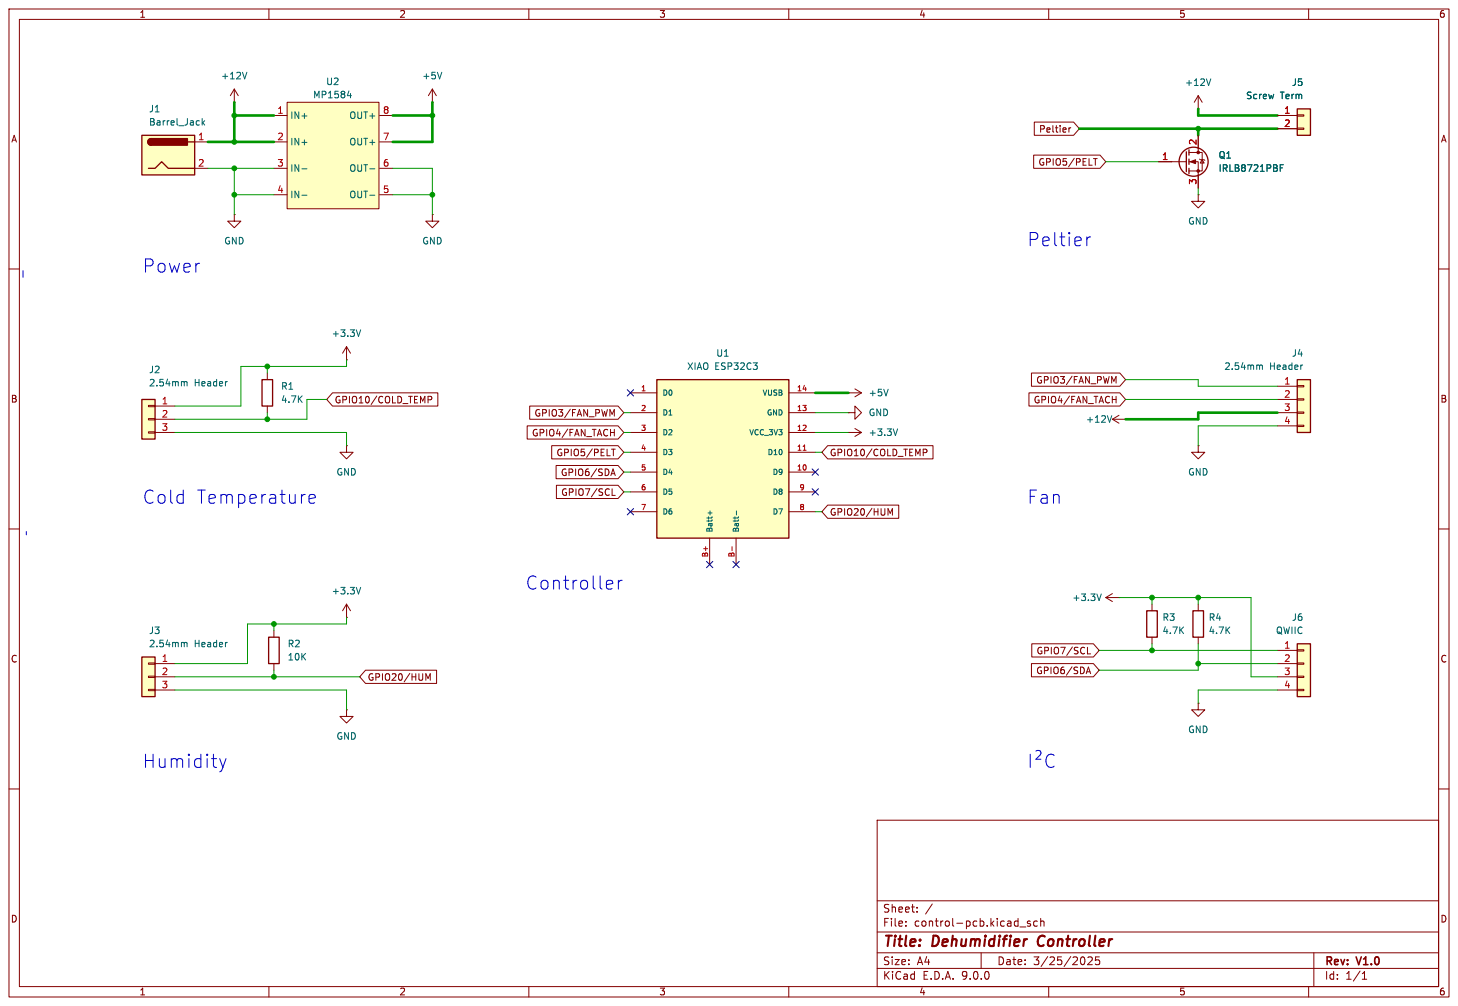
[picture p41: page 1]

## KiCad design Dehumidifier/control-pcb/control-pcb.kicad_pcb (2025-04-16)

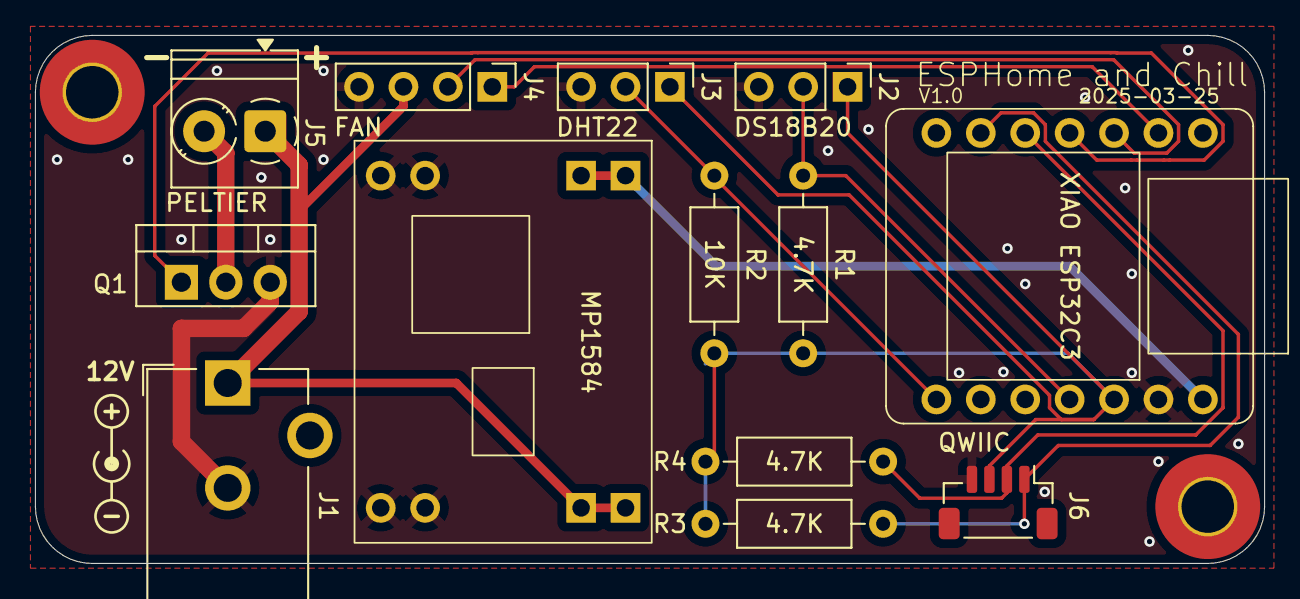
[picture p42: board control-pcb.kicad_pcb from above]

Board: 2 copper layers, 70.3 x 30.2 mm, 13 parts (0 on the bottom side), 12 nets.

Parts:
J1: Barrel_Jack; BarrelJack_CUI_PJ-102AH_Horizontal
J2, J3: 2.54mm Header; PinHeader_1x03_P2.54mm_Vertical
J4: 2.54mm Header; PinHeader_1x04_P2.54mm_Vertical
J5: Screw Term; TerminalBlock_Phoenix_PT-1,5-2-3.5-H_1x02_P3.50mm_Horizontal
J6: QWIIC; JST_SH_BM04B-SRSS-TB_1x04-1MP_P1.00mm_Vertical
Q1: IRLB8721PBF; TO-220-3_Vertical
R1, R3, R4: 4.7K; R_Axial_DIN0207_L6.3mm_D2.5mm_P10.16mm_Horizontal
R2: 10K; R_Axial_DIN0207_L6.3mm_D2.5mm_P10.16mm_Horizontal
U1: XIAO ESP32C3; XIAO_on_Sockets
U2: MP1584; MP1584_PCB

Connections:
+3.3V: J2.1, J3.1, J6.3, R1.1, R2.1, R3.1, R4.1, U1.12 (VCC_3V3)
+5V: U1.14 (VUSB), U2.7 (OUT+), U2.8 (OUT+)
+12V: J1.1, J4.3, J5.1, U2.1 (IN+), U2.2 (IN+)
GND: J1.2, J2.3, J3.3, J4.4, J6.4, Q1.3 (S), U1.13 (GND), U2.3 (IN-), U2.4 (IN-), U2.5 (OUT-), U2.6 (OUT-)
GPIO3/FAN_PWM: J4.1, U1.2 (D1)
GPIO4/FAN_TACH: J4.2, U1.3 (D2)
GPIO5/PELT: Q1.1 (G), U1.4 (D3)
GPIO6/SDA: J6.2, R4.2, U1.5 (D4)
GPIO7/SCL: J6.1, R3.2, U1.6 (D5)
GPIO10/COLD_TEMP: J2.2, R1.2, U1.11 (D10)
GPIO20/HUM: J3.2, R2.2, U1.8 (D7)
Peltier: J5.2, Q1.2 (D)

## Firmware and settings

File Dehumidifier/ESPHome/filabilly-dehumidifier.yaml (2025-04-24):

# The ESPHome configuration for the FilaBilly Dehumidifier has a lot
# of moving parts.  At the heart, it is a chiller.  The chiller keeps
# a heatsink cold so that water in the air moving past it will
# condense out.
#
# It can be run in one of three modes.
#
#  - Standalone.  It presents a web server for control and, if
#    necessary, its own Wi-Fi access point and captive portal.
#
#  - Under Home Assistant control.  It exports several entities to HA.
#
#  - As a component of the FilaBilly Humidor (FBH).  The FBH also
#    has the option to run standalone or under Home Assistant control.
#
# In any mode, the client can monitor sensors and change settings.
# Plus, there are several additional sensors and settings that are
# hidden by default.
#
# Let's start at the PID Climate component.  It monitors the chiller
# temperature, uses a PID loop to adjust power through the peltier
# output.
#
# The freeze and defrost script continuously cycle the chiller
# temperature between just below and just above freezing.  The
# temperature changes happen continuously whether the chiller is
# running or not.
# 
# There is a temperature and humidity sensor outside the chiller.
# The temperature is exposed to clients but not otherwise used.
# The humidity is used to determine when the chiller should run.
#
# The high_humidity virtual sensor calculates whether the ambient
# humidity is high enough that the chiller needs to run.  Clients
# can adjust the target humidity.
# 
# The Disable switch, which is software-only and set by clients,
# disables the chiller when set.
# 
# The fan runs when the chiller runs.  Clients can adjust the
# fan speed.  I recommend full speed if you can tolerate the noise.
# At slower speeds, you should reduce the vent opening on the
# dehumidifier's bottom.
#
# There is a software button, hidden by default, that runs a PID
# autotune process for the chiller.  The PID autotune results are
# displayed in the log, so watch the log if you run the tuning.  Then
# copy the tuned values into this configuration file and update
# the device.
#
# There are various non-dehumidifier-specific components, too.
#   - logger
#   - wifi
#   - ota
#   - captive_portal
#   - api
#   - web_server


esphome:
  name: filabilly-dehumidifier
  friendly_name: "Filabilly Dehumidifier"
  # If you have more than one FBD on your network,  uncomment.
  # name_add_mac_suffix: true

  # Automation
  on_boot:
    priority: -100
    then:
      - script.execute: defrost_script


esp32:
  board: seeed_xiao_esp32c3


# Logger.  Some of the sensors are too chatty.
# PID autotune results appear in the log.
logger:
  level: DEBUG
  logs:
    climate: INFO
    dallas.temp.sensor: INFO
    dht: INFO
    switch: INFO
    sensor: INFO


# Wi-Fi.
# Set your SSID and password.
# Secrets are explained here.
# https://esphome.io/guides/faq.html#tips-for-using-esphome
wifi:
  ssid: !secret wifi_ssid
  password: !secret wifi_password
  ap:
    ssid: "FilaBilly Dehumidifier HotSpot"
    password: !secret wifi_password


# Captive portal is a fallback when no known Wi-Fi network is found.
captive_portal:


# Over-the-Air Updates
ota:
  platform: esphome
  id: fbd_ota
  password: !secret filabilly_dehumidifier_ota


# Web Interface - used standalone and by FilaBilly Humidor
web_server:
  ota: false
  version: 3
  sorting_groups:
    - id: status_sorting_group
      name: "Status"
      sorting_weight: 10
    - id: settings_sorting_group
      name: "Settings"
      sorting_weight: 20
    - id: debug_sorting_group
      name: "Debug"
      sorting_weight: 30


# -------------------------------------------------------------------- #
# Components specific to the dehumidifier follow.  Components are in
# alphabetical order, because there is no useful ordering, and there
# are too many to visually scan.

# Home Assistant API
api:
  encryption:
    key: !secret filabilly_dehumidifier_key
  reboot_timeout: 0s


binary_sensor:

  # High Humidity: convert humidity comparison to a debounced boolean
  - platform: template
    id: high_hum_binary_sensor
    internal: true
    filters:
      - settle: 2min
    on_press:
      then:
        - script.execute: maybe_start_script
    on_release:
      then:
        - script.execute: stop_script
    lambda: |-
      float target = id(target_hum_number).state;
      float hum = id(dht_hum_sensor).state;
      if (std::isnan(target)) { return true; }
      if (std::isnan(hum)) { return true; }
      return hum > target;


button:
  - platform: template
    name: "Autotune Chiller PID"
    icon: mdi:gesture-tap-button
    disabled_by_default: true
    on_press:
      - climate.pid.set_control_parameters:
          id: chiller_climate
          kp: 0.0
          ki: 0.0
          kd: 0.0
      - climate.pid.autotune: chiller_climate
    # web server version 3
    web_server:
      sorting_group_id: debug_sorting_group
      sorting_weight: 60
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

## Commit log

2025-03-27 Initial commit: dehumidifier control board v1.0
    [v0.kicad_pcb, v0.kicad_sch]
2025-04-16 Add revision V1.0 and date 3/25/2025 to schematic
    [v0.kicad_sch]
2025-04-16 Rename dehumidifier control PCB to 'Control PCB/control-pcb'
    [control-pcb.kicad_pcb, control-pcb.kicad_sch]
2025-04-16 Commit V1.0 gerber ZIP file
2025-04-16 Move 'Control PCB/control-pcb' to control-pcb
    [control-pcb.kicad_pcb, control-pcb.kicad_sch]
2025-04-20 First draft of the dehumidifier assembly guide
2025-04-20 Dehumidifier assembly guide is formatted. Still needs some photos.
2025-04-20 Add back cover to Assembly Guide
2025-04-24 Dehumidifier ESPHome config PID tuning and icon fix
    - removed PID controller derivative_averaging_samples
    - Chiller Temperature icon is now mdi:snowflake-thermometer
    [filabilly-dehumidifier.yaml]
2025-04-26 Update Assembly Guide with more photos, better text and annotations
2025-04-28 Add printed files: .STL, .3mf, .f3d, and .STEP
    [2X Half Seal.stl, Bottom Vent Slider.stl, DHT22 Standoff.stl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]
2025-04-28 Minor edits to Assembly Guide
2025-12-27 Add control PCB schematic as PDF
2025-12-27 Add fan and surround STLs and images
    [Cutting Guide.stl, Dummy Bottom.stl, Dummy Fan Hub.stl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]
2026-10-31 Add Filabilly Mount
